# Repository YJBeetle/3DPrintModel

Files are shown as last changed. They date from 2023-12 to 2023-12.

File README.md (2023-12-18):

# 3DPrintModel

这个仓库用于存储一些个人绘制的用于3D打印的模型的地方，部分子文件夹中可能包含3D打印之外的，如适用于激光雕刻切割或车铣加工的图纸。

因为可能会很杂，因此不再每个项目单独开仓库，而是统一放在这一个仓库里。

大多项目我将使用FreeCAD绘制，因为这可以确保更多的用户得以打开与编辑它们，我使用的是[realthunder的FreeCAD分支](https://github.com/realthunder/FreeCAD)

每个子文件夹中会随缘附一些说明，大部分我会将导出的模型文件甚至切片参数一并提交。

3mf文件是使用Bambu Studio生成，内含了切片参数和GCODE，请勿直接打印GCODE，请重新切片后打印，如直接打印可能造成不可预料的后果，特此警告。

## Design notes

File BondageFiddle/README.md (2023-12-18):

# BondageFiddle

这是一个用于BDSM目的的模型，用于拘束他人或者自我拘束。

特此警告⚠️：严禁将此模型用于强迫他人的目的。

## 关于尺寸

在正式制造之前，请先打印[Test.obj](./Output/Test.obj)模型确认尺寸匹配，若尺寸不合适，请打开[Fiddle.FCStd](./Fiddle.FCStd)，找到Reference部件，并编辑ReferenceSize草图，修改为适合的尺寸后重新导出对应模型。

## 制造说明

这个模型有两个版本，可以使用3D打印或用激光切割雕刻来制造。

### 3D打印

准备以下标准件：

| 名字 | 数量 |
| --- | ---- |
| M3x14内六角杯头螺丝 | 30 |
| M3六角螺母 | 30 |
| M4x14内六角杯头螺丝 | 3 |
| M4六角螺母 | 3 |

使用PETG材料打印以下文件，参数使用100%填充，-0.1mm的XY外形尺寸补偿，0.1mm的XY孔洞尺寸补偿。

| 模型文件                                                      |
| ------------------------------------------------------------- |
| [Bolt](./Output/Bolt.obj)                                     |
| [Left-Arch-Primary-A](./Output/Left-Arch-Primary-A.obj)       |
| [Left-Arch-Primary-B](./Output/Left-Arch-Primary-B.obj)       |
| [Left-Arch-Secondary-A](./Output/Left-Arch-Secondary-A.obj)   |
| [Left-Arch-Secondary-B](./Output/Left-Arch-Secondary-B.obj)   |
| [Left-Clip-A](./Output/Left-Clip-A.obj)                       |
| [Left-Clip-B](./Output/Left-Clip-B.obj)                       |
| [Right-Arch-Primary-A](./Output/Right-Arch-Primary-A.obj)     |
| [Right-Arch-Primary-B](./Output/Right-Arch-Primary-B.obj)     |
| [Right-Arch-Secondary-A](./Output/Right-Arch-Secondary-A.obj) |
| [Right-Arch-Secondary-B](./Output/Right-Arch-Secondary-B.obj) |
| [Right-Clip-A](./Output/Right-Clip-A.obj)                     |
| [Right-Clip-B](./Output/Right-Clip-B.obj)                     |

使用TPU材料打印[Shackle](./Output/Shackle.obj)，参数使用100%填充，-0.1mm的XY外形尺寸补偿，0.1mm的XY孔洞尺寸补偿，数量4。

效果图：

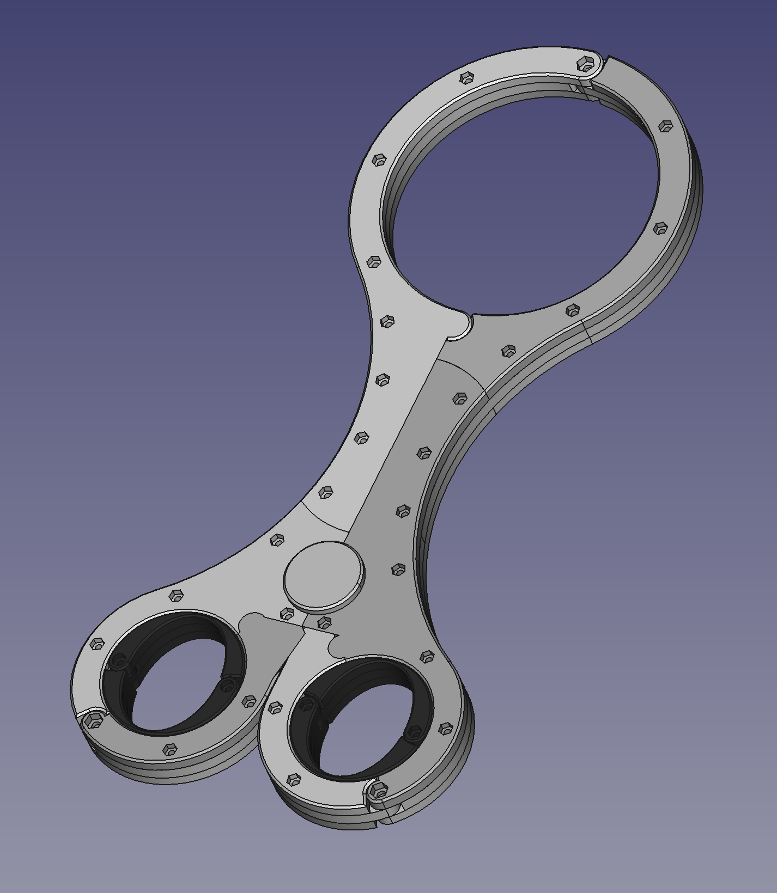
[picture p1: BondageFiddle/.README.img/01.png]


### 激光切割

激光切割可以生产其中的大部分部件，但是少量部件依然需要3D打印TPU材料来制造。

准备以下标准件：

| 名字 | 数量 |
| --- | ---- |
| M3x14内六角杯头螺丝 | 33 |
| M3x32内六角杯头螺丝 | 2 |
| M3六角螺母 | 35 |

准备一张 400x500x6(mm) 的亚克力板。

先以[LaserEngravingDraft.dxf](./Output/LaserEngravingDraft.dxf)填充后进行雕刻，雕刻深度为3mm左右。

保持坐标不动，再以[LaserCutDraft.dxf](./Output/LaserCutDraft.dxf)的外形线进行切割，即可完成。

使用TPU材料打印[ShackleForLaserCut](./Output/ShackleForLaserCut.obj)，参数使用100%填充，-0.1mm的XY外形尺寸补偿，0.1mm的XY孔洞尺寸补偿，数量4。

效果图：

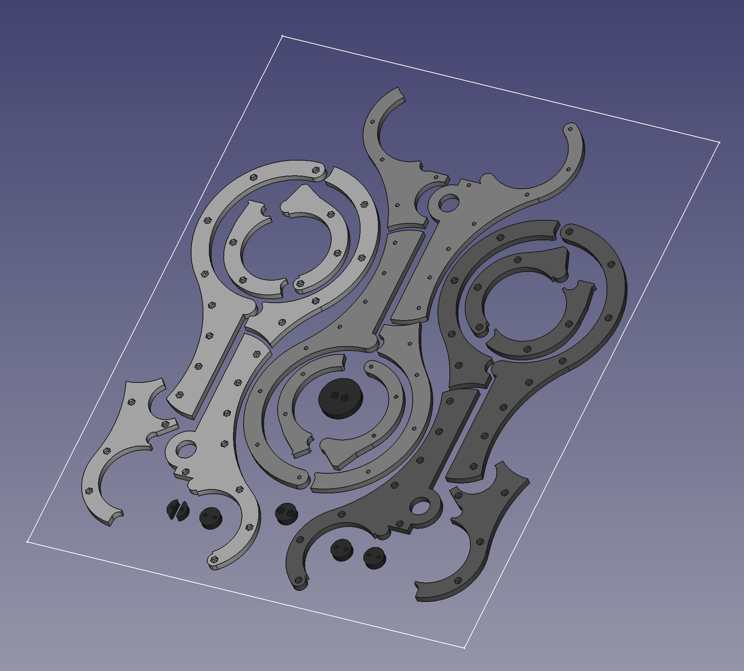
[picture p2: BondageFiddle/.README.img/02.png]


## 感谢

本项目参考了[这个模型](https://www.printables.com/model/216352-bdsm-modern-self-bondage-fiddle-with-rotating-hand)，重新绘制后改善了该模型上一些尖锐的地方以及使之需要更少的支撑。

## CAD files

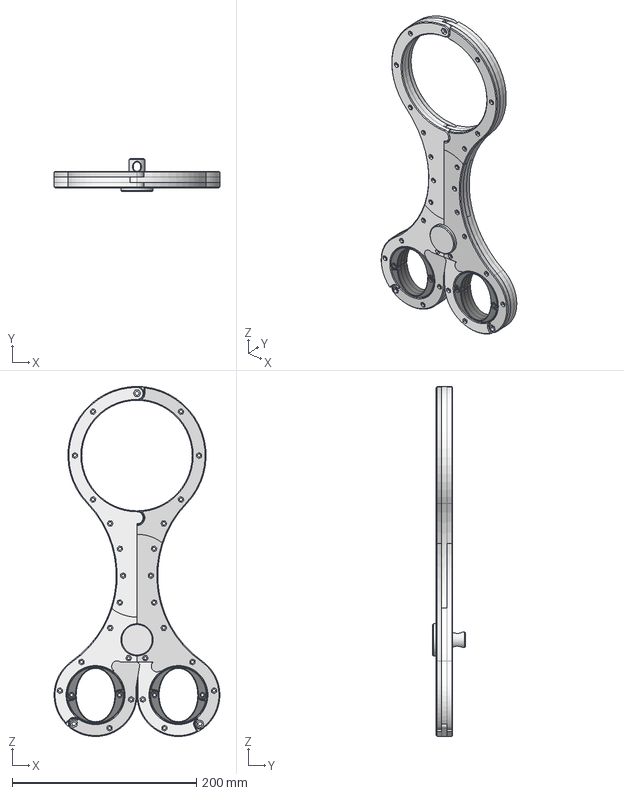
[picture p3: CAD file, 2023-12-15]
BondageFiddle/Fiddle.FCStd
180.0 x 36.0 x 380.0 mm
Right-Arch-Primary-A
Right-Arch-Primary-B
Left-Arch-Primary-A
Left-Arch-Primary-B
Right-Arch-Secondary-A
Right-Arch-Secondary-B
Left-Arch-Secondary-A
Left-Arch-Secondary-B
Right-Clip-A
Right-Clip-B
Left-Clip-A
Left-Clip-B
Shackle x 4
Bolt

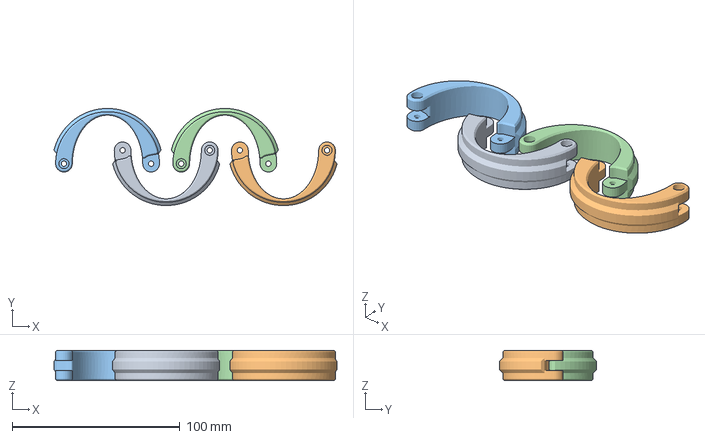
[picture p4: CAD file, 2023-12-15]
BondageFiddle/Output/Shackle.3mf
168.9 x 57.9 x 18.0 mm
Shackle.obj x 4

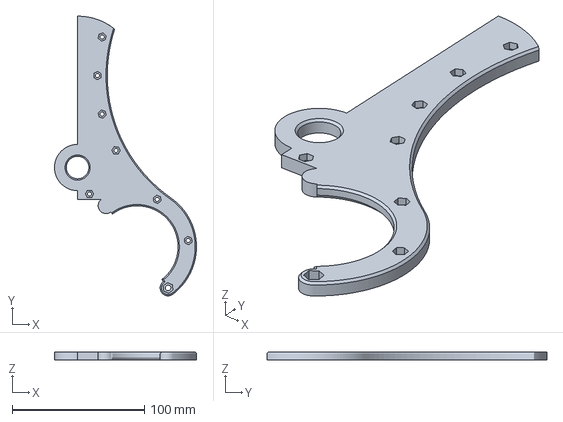
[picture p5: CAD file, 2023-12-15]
BondageFiddle/Output/Right-Arch-Secondary-B.3mf
107.5 x 211.8 x 6.00 mm

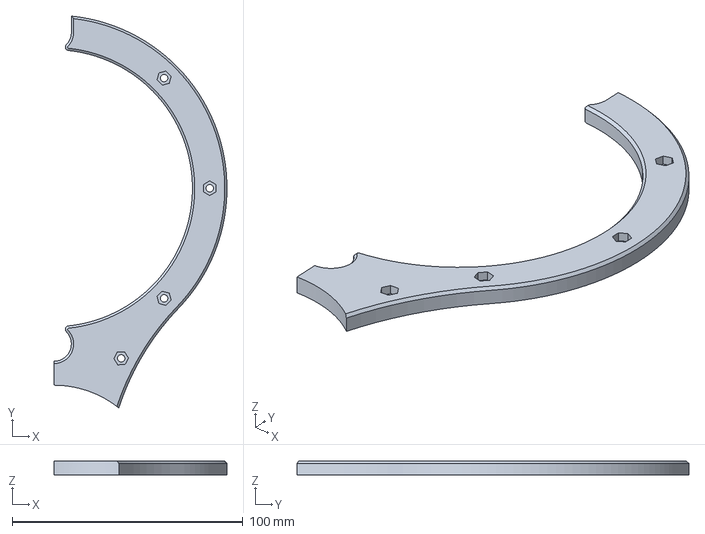
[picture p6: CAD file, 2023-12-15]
BondageFiddle/Output/Right-Arch-Primary-B.3mf
75.0 x 169.9 x 6.00 mm

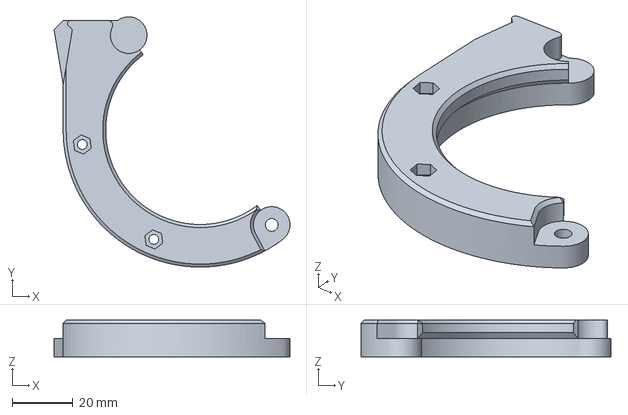
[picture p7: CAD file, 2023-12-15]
BondageFiddle/Output/Right-Clip-A.3mf
77.5 x 82.1 x 12.0 mm

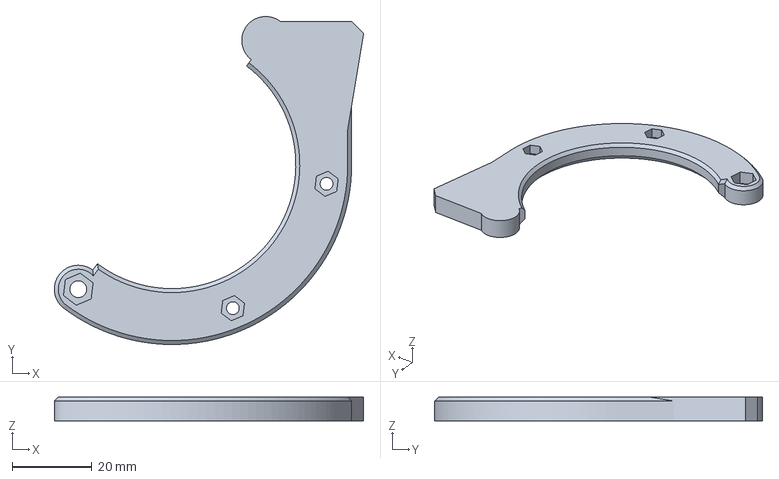
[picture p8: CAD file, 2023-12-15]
BondageFiddle/Output/Left-Clip-B.3mf
77.5 x 82.1 x 6.00 mm

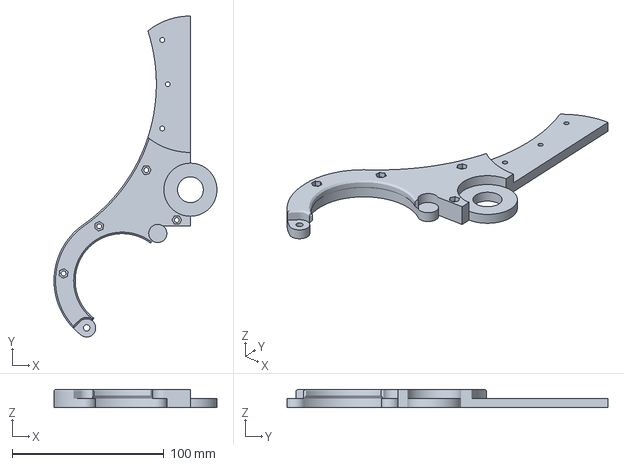
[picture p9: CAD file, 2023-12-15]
BondageFiddle/Output/Left-Arch-Secondary-A.3mf
107.5 x 211.8 x 12.0 mm

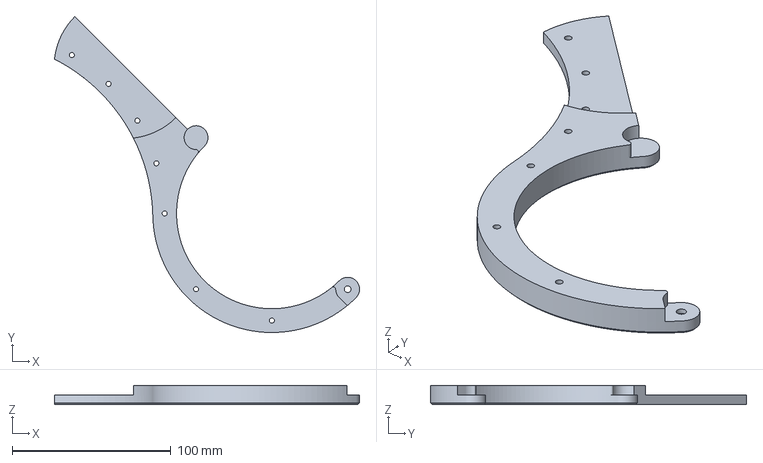
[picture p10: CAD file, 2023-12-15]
BondageFiddle/Output/Left-Arch-Primary-A.3mf
192.2 x 199.0 x 12.0 mm

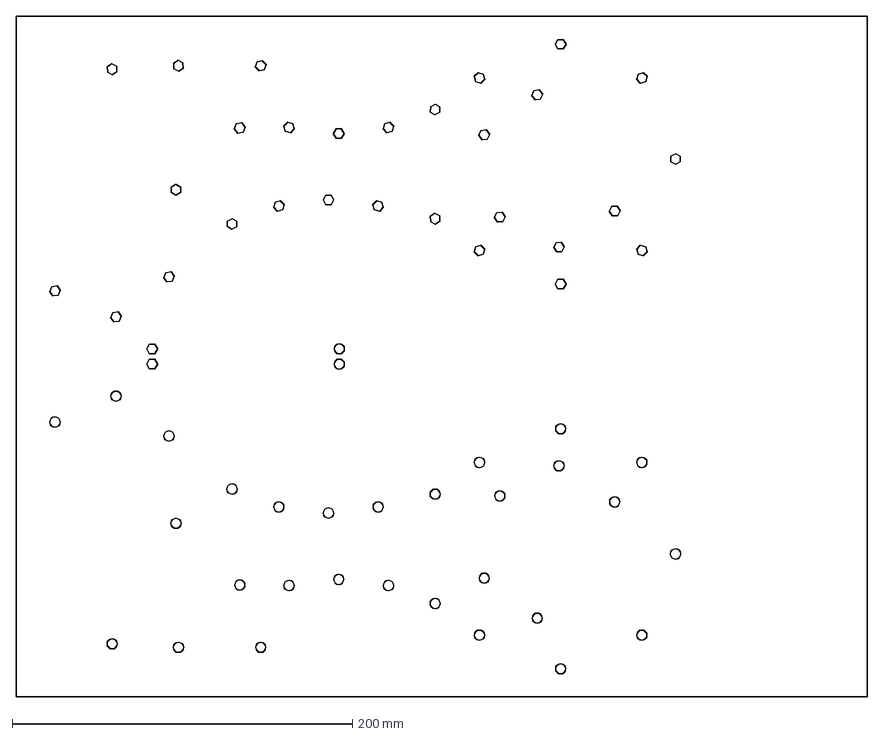
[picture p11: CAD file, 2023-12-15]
BondageFiddle/Output/LaserEngravingDraft.dxf
500.0 x 400.0 mm

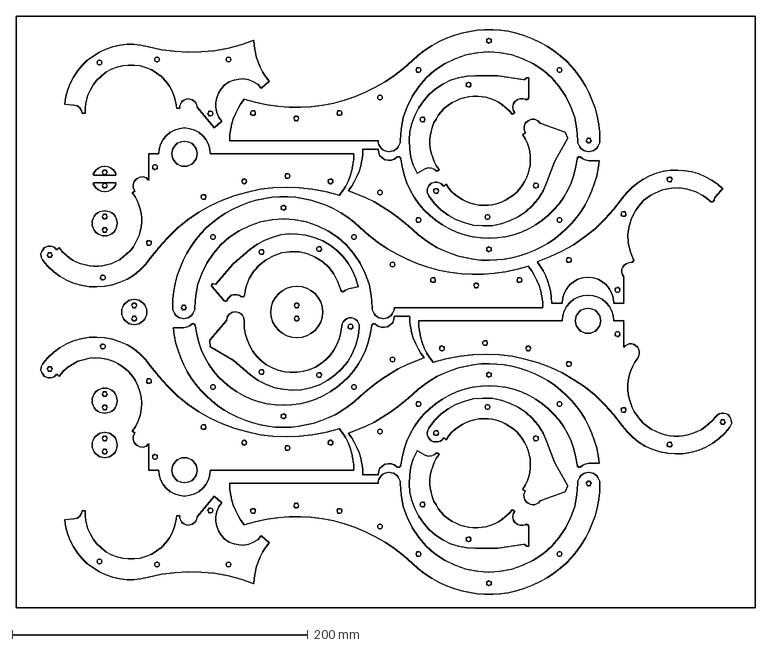
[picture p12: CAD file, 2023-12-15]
BondageFiddle/Output/LaserCutDraft.dxf
500.0 x 400.0 mm

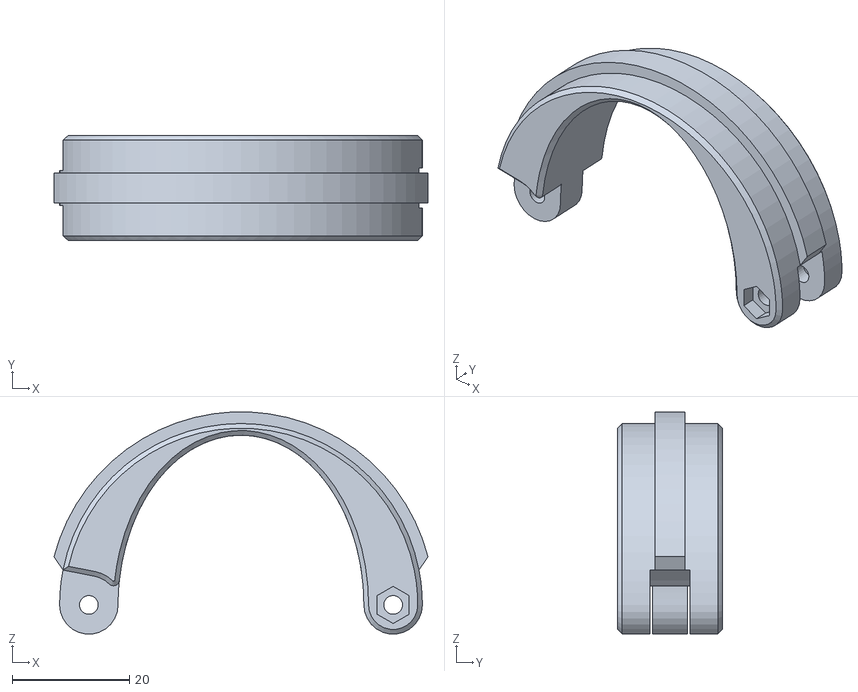
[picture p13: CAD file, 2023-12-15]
BondageFiddle/Output/ShackleForLaserCut.obj
63.9 x 18.0 x 37.9

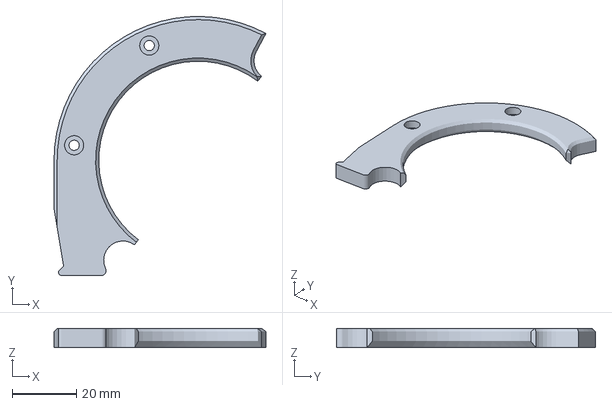
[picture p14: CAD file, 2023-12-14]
BondageFiddle/Output/Right-Clip-B.3mf
66.2 x 80.9 x 6.00 mm

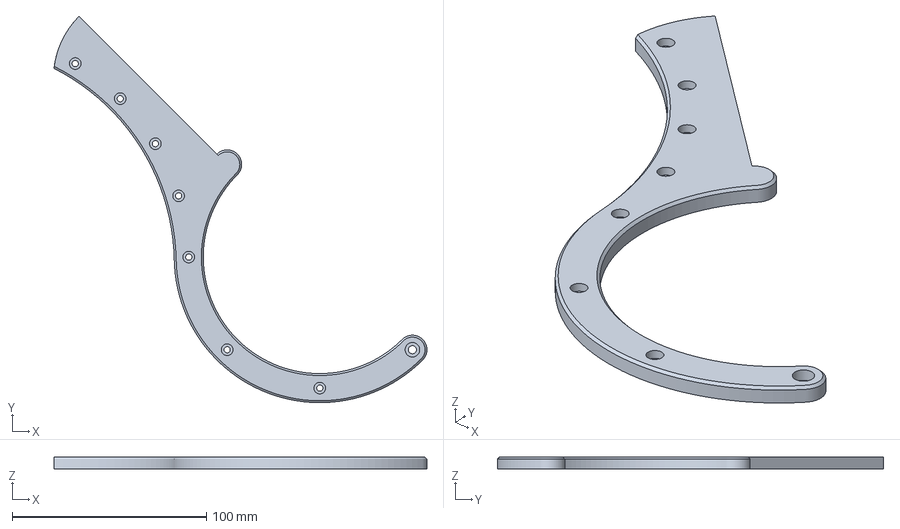
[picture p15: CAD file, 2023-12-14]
BondageFiddle/Output/Left-Arch-Primary-B.3mf
192.2 x 199.0 x 6.00 mm

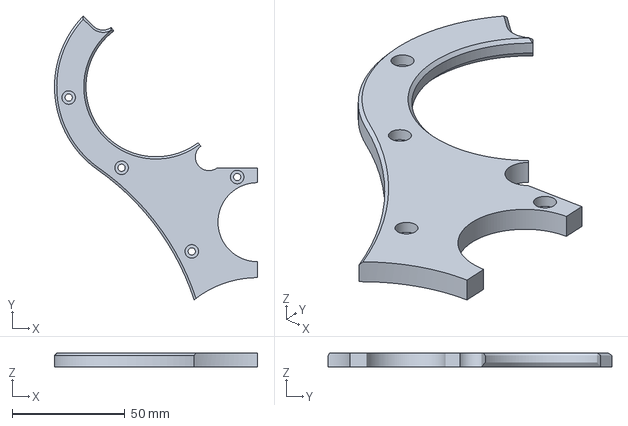
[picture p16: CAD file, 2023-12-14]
BondageFiddle/Output/Left-Arch-Secondary-B.3mf
90.0 x 125.8 x 6.00 mm

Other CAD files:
BondageFiddle/Output/Right-Arch-Secondary-A.3mf
BondageFiddle/Output/Right-Arch-Primary-A.3mf
BondageFiddle/Output/Left-Clip-A.3mf
BondageFiddle/Output/Test.3mf
BondageFiddle/Output/Bolt.3mf
BondageFiddle/Output/Bolt.obj
BondageFiddle/Output/Left-Arch-Primary-A.obj
BondageFiddle/Output/Left-Arch-Primary-B.obj
BondageFiddle/Output/Left-Arch-Secondary-A.obj
BondageFiddle/Output/Left-Arch-Secondary-B.obj
BondageFiddle/Output/Left-Clip-A.obj
BondageFiddle/Output/Left-Clip-B.obj
BondageFiddle/Output/Right-Arch-Primary-A.obj
BondageFiddle/Output/Right-Arch-Primary-B.obj
BondageFiddle/Output/Right-Arch-Secondary-A.obj
BondageFiddle/Output/Right-Arch-Secondary-B.obj
BondageFiddle/Output/Right-Clip-A.obj
BondageFiddle/Output/Right-Clip-B.obj
BondageFiddle/Output/Shackle.obj
BondageFiddle/Output/Test.obj

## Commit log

2023-12-14 add BondageFiddle
    [Fiddle.FCStd]
2023-12-14 add BondageFiddle output model
    [Fiddle-MainBody001.3mf, Fiddle-MainBody001.obj, Fiddle-MainBody002.3mf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]
2023-12-14 rename model
    [Bolt.3mf, Bolt.obj, Fiddle.FCStd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]
2023-12-14 尺寸调整 允许的手腕大小+2mm
    [Fiddle.FCStd]
2023-12-14 转动部分重构
    [Fiddle.FCStd]
2023-12-14 更新模型
    [Left-Arch-Secondary-A.3mf, Left-Arch-Secondary-A.obj, Left-Arch-Secondary-B.3mf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]
2023-12-14 更新模型参数
    [Bolt.3mf, Left-Arch-Primary-A.3mf, Left-Arch-Primary-B.3mf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]
2023-12-14 一个用于激光切割的版本
    [Fiddle.FCStd]
2023-12-14 激光切割图纸
    [Fiddle.FCStd, Page.dxf, Page001.dxf]
2023-12-15 激光切割改加间隙
    [Fiddle.FCStd, Page.dxf, Page001.dxf]
2023-12-15 修改适用于激光雕刻的手腕模型
    [Fiddle.FCStd, ShackleForLaserCut.obj]
2023-12-15 重新排列 更紧凑 以便在一个400x500的板子可以雕刻
    [Fiddle.FCStd]
2023-12-15 加一个激光切割的塞子
    [Fiddle.FCStd, LaserCutDraft.dxf, LaserEngravingDraft.dxf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]
2023-12-15 螺纹深度加0.5mm 更适应标准螺纹长度
    [Fiddle.FCStd, Left-Arch-Primary-A.3mf, Left-Arch-Primary-A.obj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]
2023-12-15 修正Shackle的若干问题
    [Fiddle.FCStd]
2023-12-15 为了更好的转动 Shackle的厚度减少1mm
    [Fiddle.FCStd, Shackle.3mf, Shackle.obj]
2023-12-18 添加了说明文件
